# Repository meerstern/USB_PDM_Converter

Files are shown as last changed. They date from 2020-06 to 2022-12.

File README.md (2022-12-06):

# USB_PDM_Converter
USB-PDM Converter with CS53L30 &amp; CP2615

## 概要 
  * [USB オーディオブリッジIC CP2615][1]と[ADコンバータ CS53L30][2]を使用したUSB-PDM変換基板です  
  * 2個のデジタルPDM出力MEMSマイクをUSBオーディオデバイス(ステレオ)に変換します  
  * 24bit、44.1kHz/48kHzサンプリングで変換します  
  * デジタルPDM出力MEMSマイクの評価や動作確認に便利です  
  * デジタルPDM出力MEMSマイク電源は既定値で2.75Vです 
  * デジタルPDM出力MEMSマイククロックは既定値で3MHzです 
  * 2個のPDM出力MEMSマイクをUSBオーディオデバイスとして認識するためのパラメータを予め書き込んでおります  
  * OS標準のUSBオーディオデバイスとして認識されるため、ドライバは不要です  
  * [Simplicity Studio][3]を用いたCP2615のパラメータ書き換え例(デジタルMIC、アナログMIC)を用意しています  
  * [デジタル出力MEMSマイク変換基板][4]を2つ接続可能です  
  * デジタルPDM出力MEMSマイク1つの場合はモノラル出力として利用可能です  
  * サイズ40mm x50mm、M3穴x2、間隔34mm  

## 注意
  * PDM出力マイクは付属しておりませんので別途ご用意ください  
  * CS53L30の設定を変更する場合はCP2615のパラメータ変更が必要です  
  * 本変換基板とPDM出力マイクとの接続ケーブルはノイズ低減のため、30mm程度以下にしてください  
  * CP2615のパラメータを変更する場合は[Simplicity Studio][3]が必要です  
  * CP2615のパラメータを変更する場合はPIDを0xEA93に変更したCP2112が必要です  
  * CS53L30は4つのマイクを接続可能ですが、CP2615の制約で同時接続できるマイクは最大2つです  
  * MIC2側を使用する場合はR3をRX1に置き換えてください  
  * アナログMEMSマイクを使用する場合はCP2615のパラメータ書き換えが必要です  
  * CP2615はFlashベースのため、パラメータ変更の回数制約はありません  
 
## 販売サイト
  * [スイッチサイエンス][5]

## 告知
  * CP2615は生産完了予定品となっています 新規開発用途には向いていません  
  * 21年8月から22年4月頃販売の製品の一部に誤ったパラメータが書き込まれた製品があることが判明しました  
  * 購入後、マイクとして動作しない等が見られた場合はお手数ですがCrescentまでお問い合わせください  

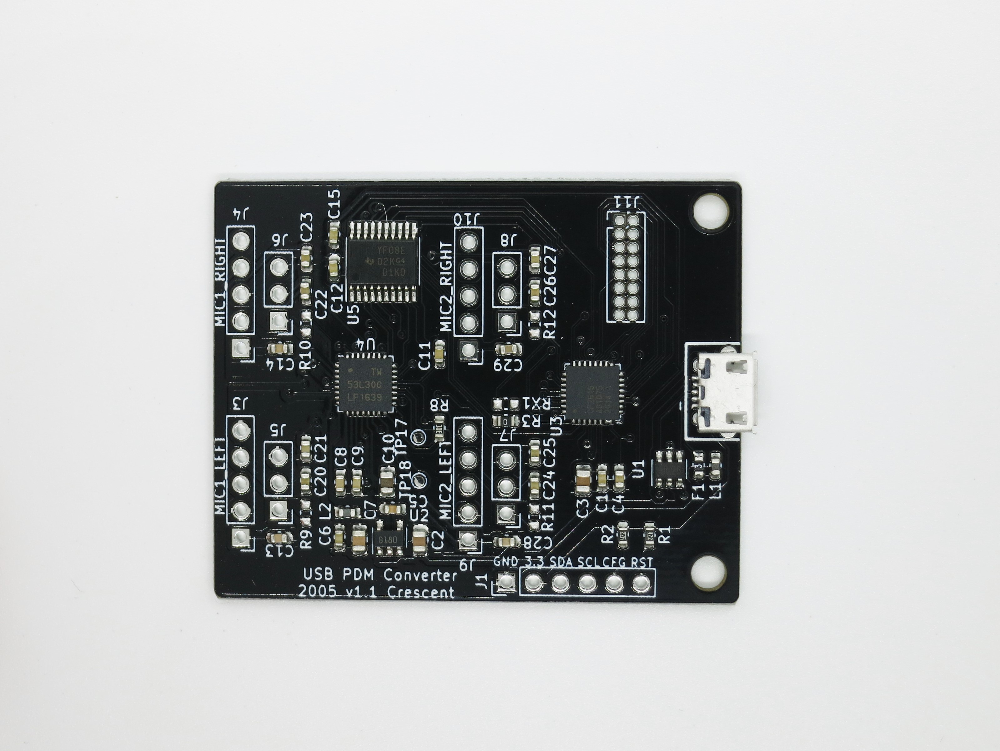
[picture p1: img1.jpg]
   
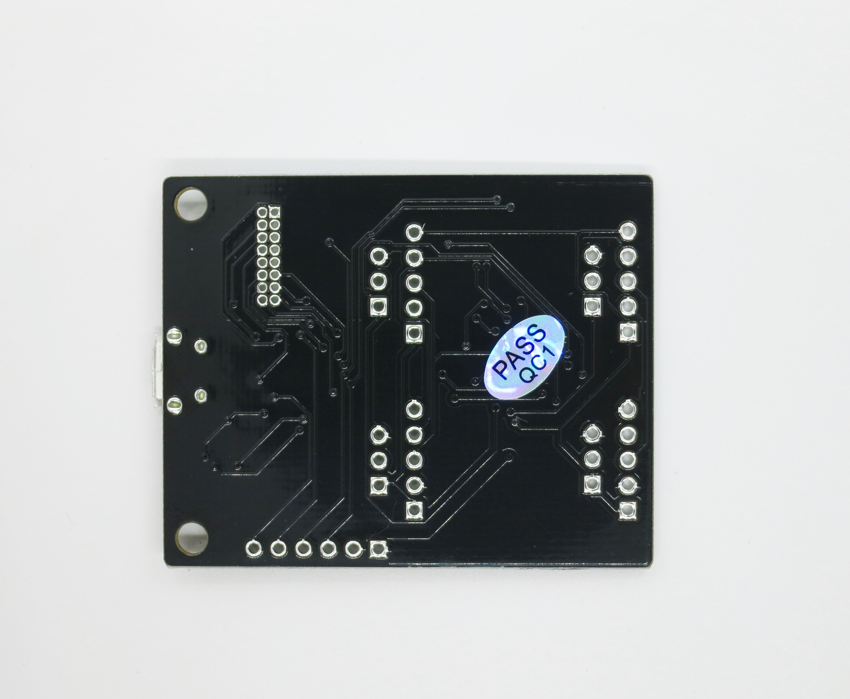
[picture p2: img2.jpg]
   
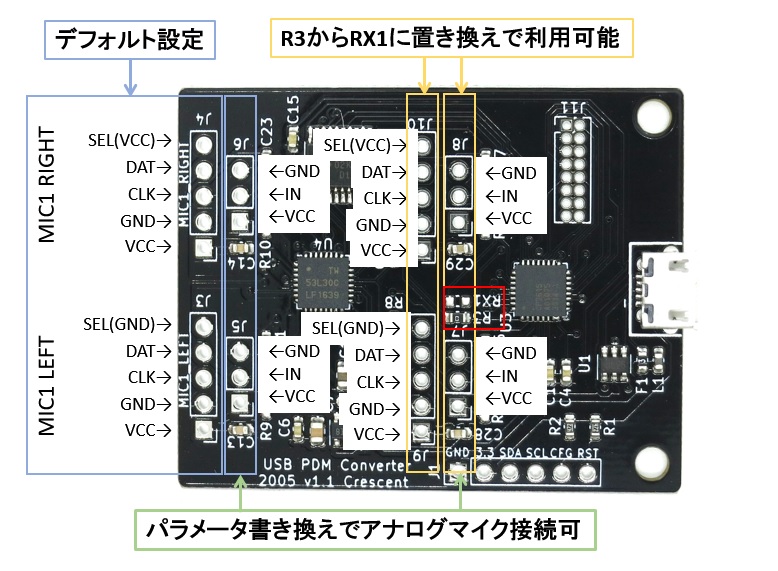
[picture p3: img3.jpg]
   
  
[1]: https://jp.silabs.com/interface/usb-audio-bridges/device.cp2615
[2]: https://www.cirrus.com/products/cs53l30/
[3]: https://jp.silabs.com/products/development-tools/software/simplicity-studio
[4]: https://www.switch-science.com/catalog/3379/
[5]: https://www.switch-science.com/products/6488

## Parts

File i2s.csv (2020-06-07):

ID | 参照記号 | パッケージ | 数 | 名称 | Supplier and ref
1 | U5 | TSSOP-20_4.4x6.5mm_P0.65mm | 1 | TXS0108EPW
2 | C15,C12,C11,C9,C6,C1 | C_0603_1608Metric | 6 | 0.1u
3 | J11 | PinHeader_2x08_P1.27mm_Vertical | 1 | Conn_02x08_Odd_Even
4 | TP18 | TestPoint_Pad_D1.0mm | 1 | MUTE
5 | TP17 | TestPoint_Pad_D1.0mm | 1 | SYNC
6 | RX1,R3 | R_0603_1608Metric | 2 | 0
7 | L2,L1 | L_0603_1608Metric | 2 | Ferrite Beads
8 | C3,C10 | C_0805_2012Metric | 2 | 4.7u
9 | REF1,REF2 | MountingHole_3.2mm_M3 | 2 | MountingHole_3.2mm_M3
10 | U4 | QFN-32-1EP_5x5mm_P0.5mm_EP3.1x3.1mm | 1 | CS53L30CZ
11 | U3 | QFN-32-1EP_5x5mm_P0.5mm_EP3.1x3.1mm | 1 | CP2615
12 | U2 | SOT-23-5 | 1 | LD3985M18R_SOT23
13 | U1 | SOT-23-6 | 1 | USBLC6-2
14 | R12,R11,R10,R9 | R_0603_1608Metric | 4 | NM
15 | R8 | R_0603_1608Metric | 1 | 20k
16 | R2,R1 | R_0603_1608Metric | 2 | 4.7k
17 | J10 | PinHeader_1x05_P2.54mm_Vertical | 1 | MIC2_RIGHT
18 | J9 | PinHeader_1x05_P2.54mm_Vertical | 1 | MIC2_LEFT
19 | J8 | PinHeader_1x03_P2.54mm_Vertical | 1 | MIC4
20 | J7 | PinHeader_1x03_P2.54mm_Vertical | 1 | MIC3
21 | J6 | PinHeader_1x03_P2.54mm_Vertical | 1 | MIC2
22 | J5 | PinHeader_1x03_P2.54mm_Vertical | 1 | MIC1
23 | J4 | PinHeader_1x05_P2.54mm_Vertical | 1 | MIC1_RIGHT
24 | J3 | PinHeader_1x05_P2.54mm_Vertical | 1 | MIC1_LEFT
25 | J2 | CONN-10118194-0001LF-FCI | 1 | USB_B_Micro
26 | J1 | PinHeader_1x06_P2.54mm_Vertical | 1 | Cfg
27 | F1 | Fuse_0603_1608Metric | 1 | Fuse
28 | C29,C28,C14,C13 | C_0603_1608Metric | 4 | 0.47u
29 | C27,C26,C25,C24,C23,C22,C21,C20,C4 | C_0603_1608Metric | 9 | 1u
30 | C8 | C_0603_1608Metric | 1 | 2.2u
31 | C7,C2 | C_0805_2012Metric | 2 | 10u
32 | C5 | C_0603_1608Metric | 1 | 0.01u

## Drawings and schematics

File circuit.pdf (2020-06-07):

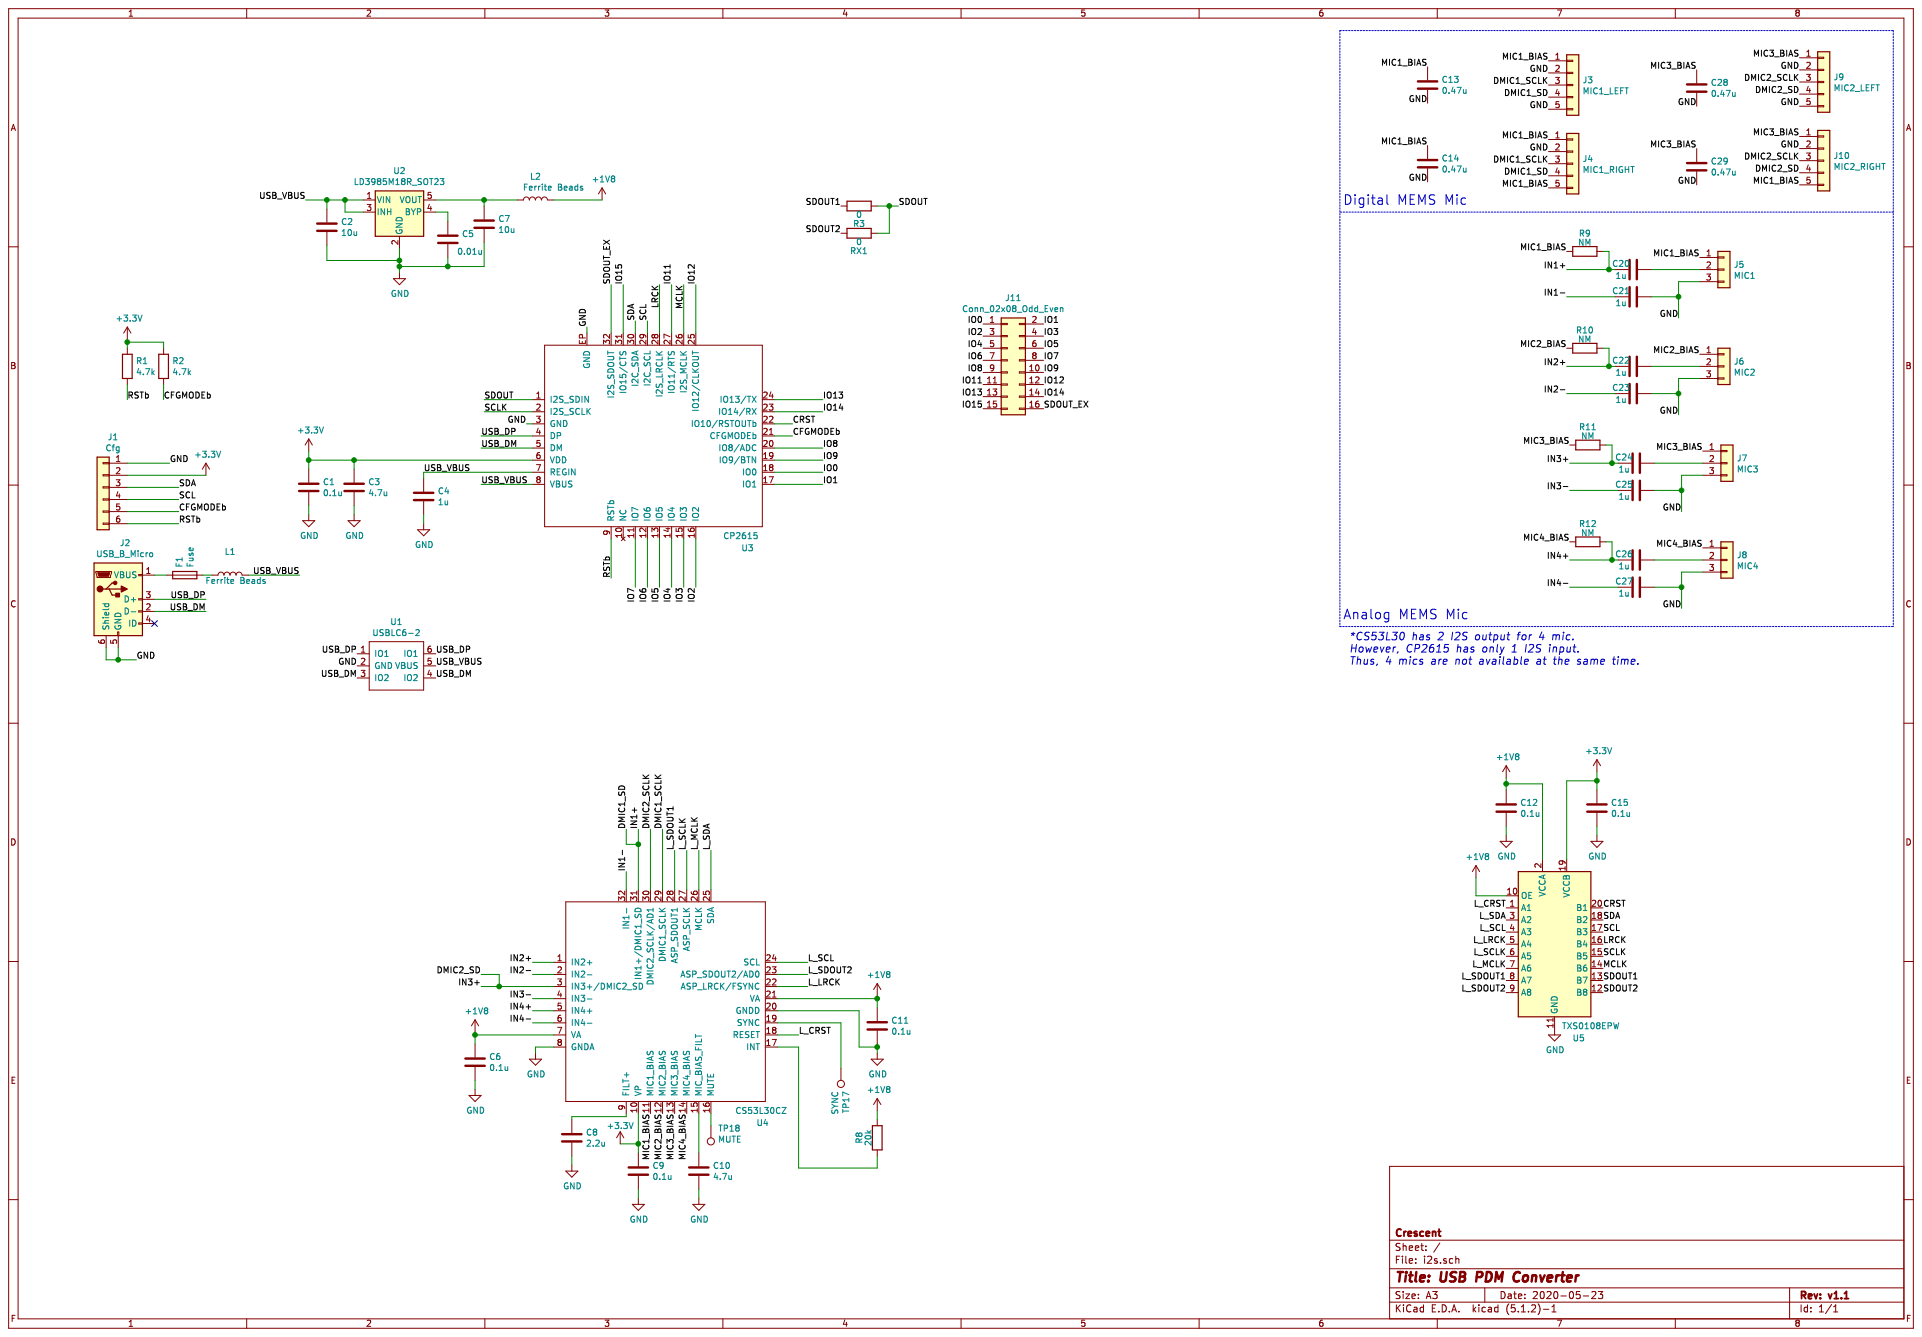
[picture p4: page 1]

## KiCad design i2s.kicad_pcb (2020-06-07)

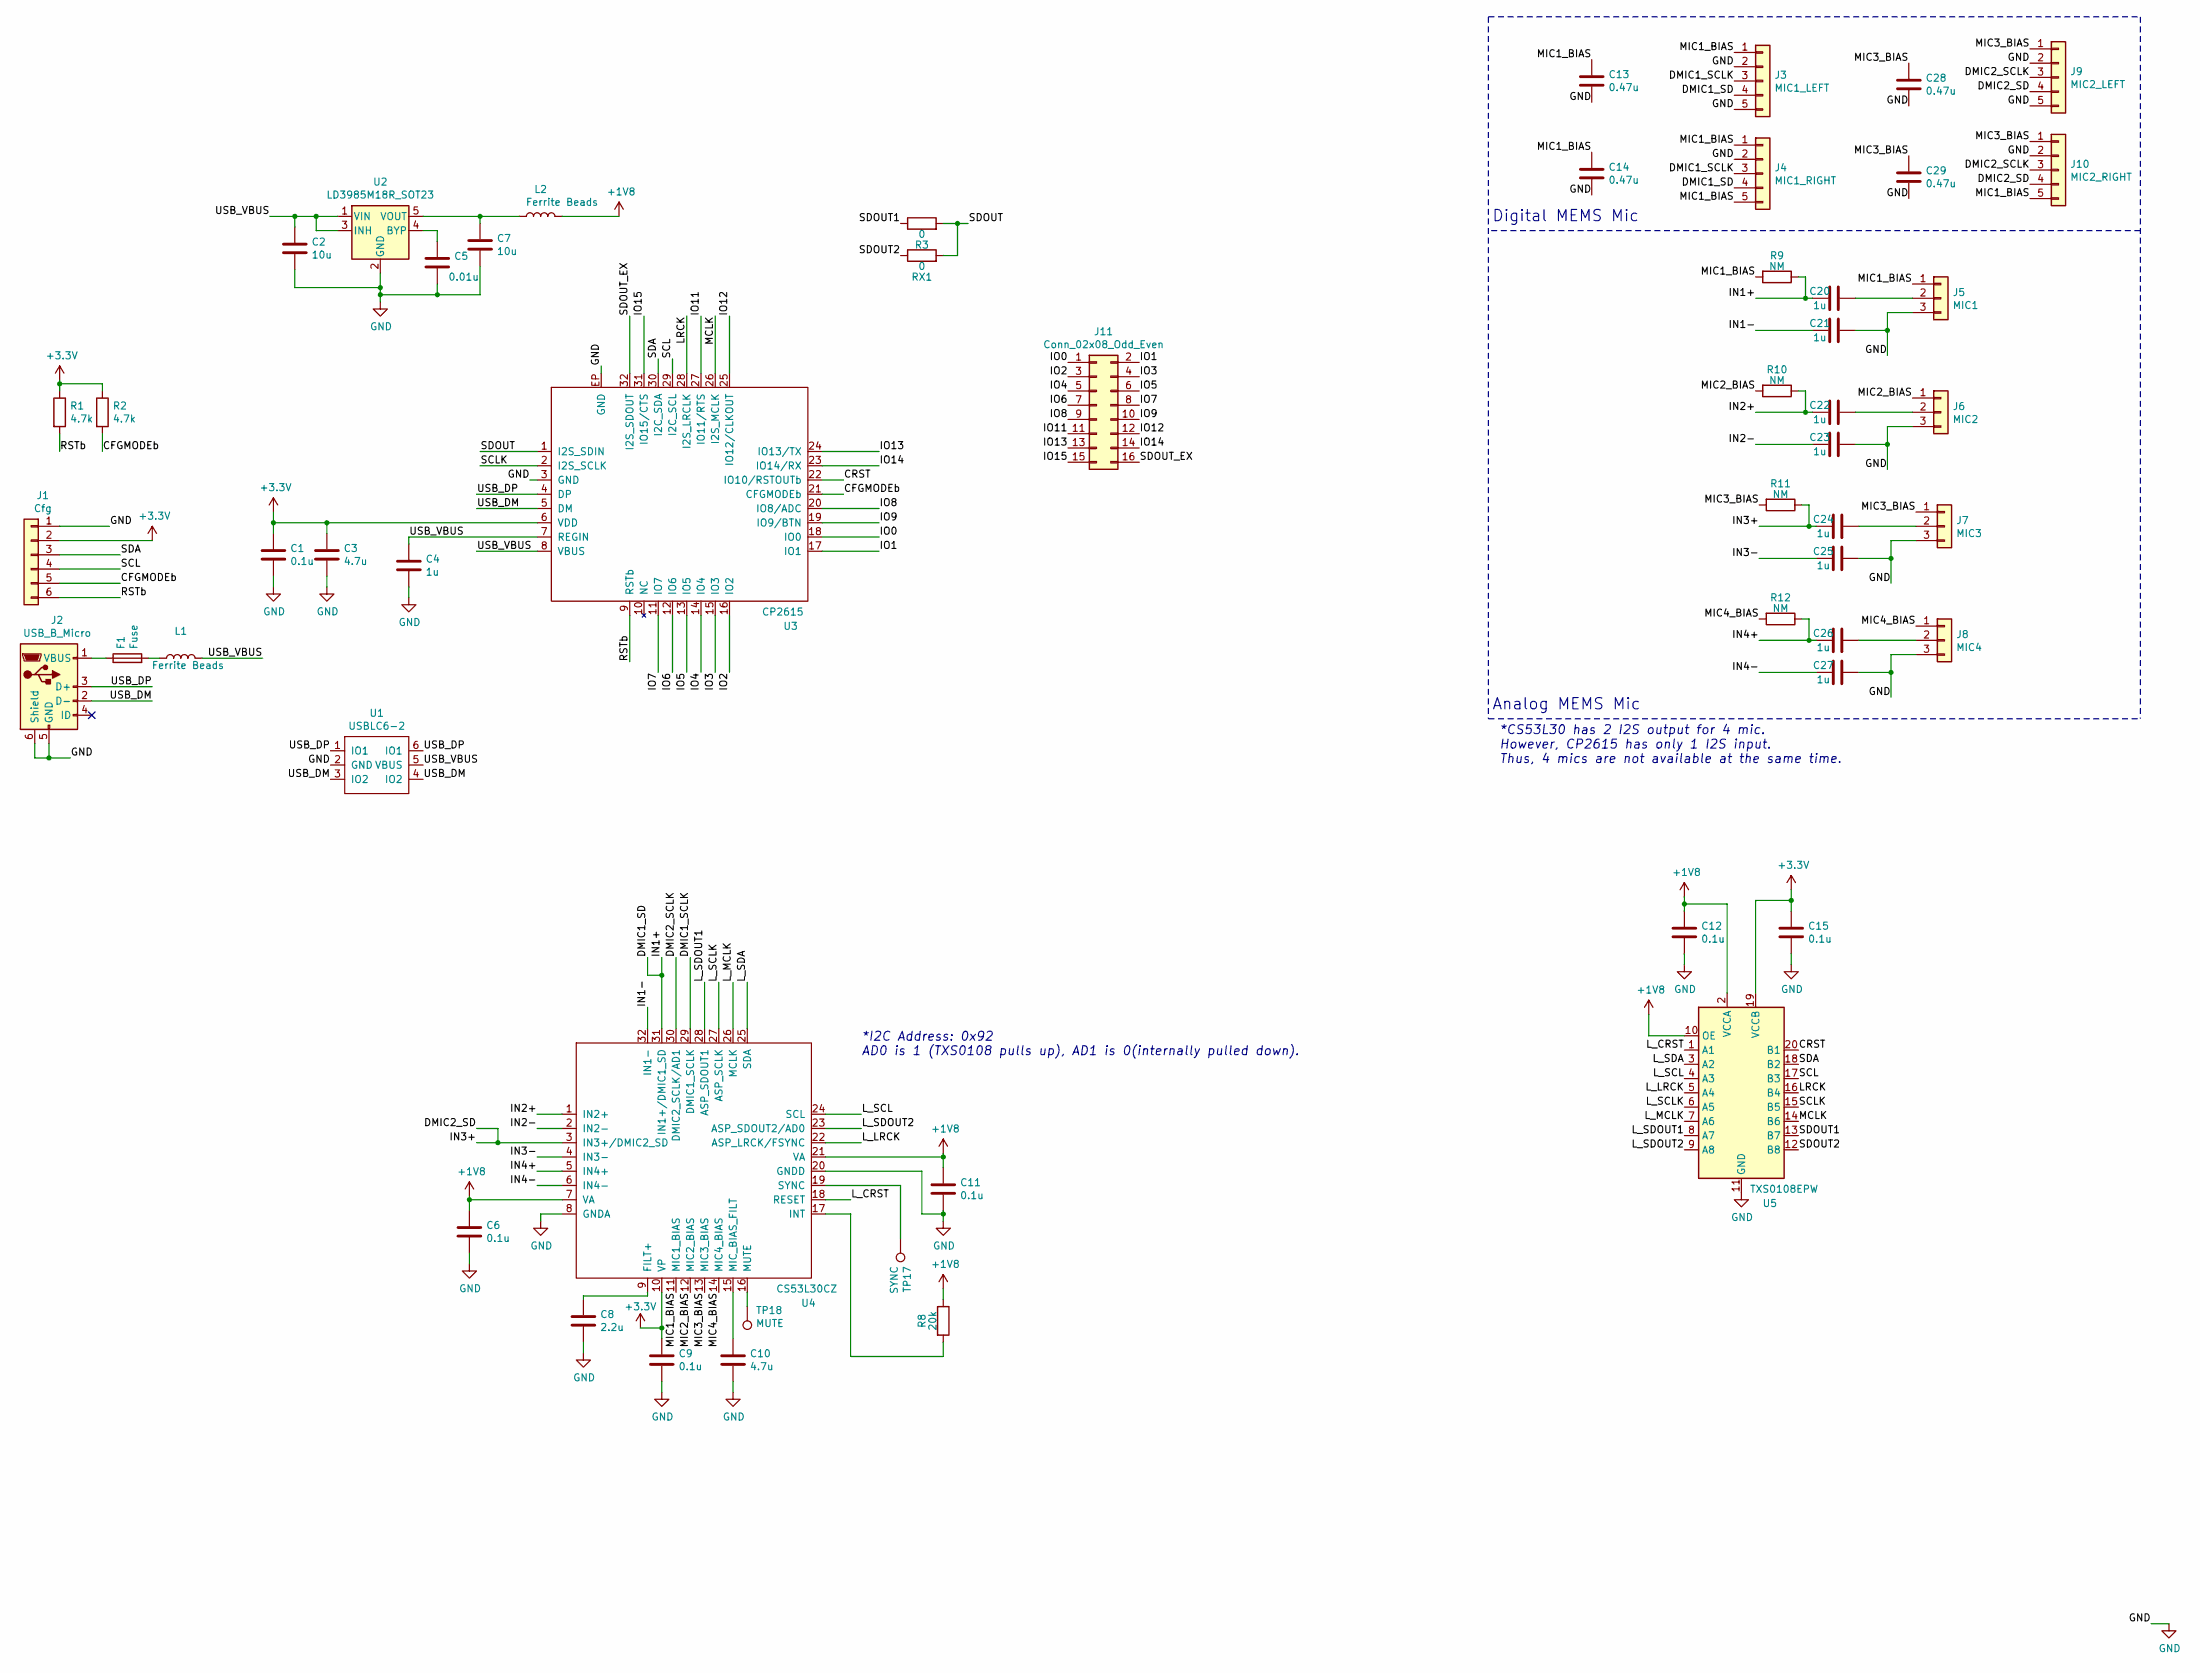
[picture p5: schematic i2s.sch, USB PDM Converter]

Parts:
C1, C6, C9, C11, C12, C15: 0.1u; C_0603_1608Metric
C2, C7: 10u; C_0805_2012Metric
C3, C10: 4.7u; C_0805_2012Metric
C4, C20, C21, C22, C23, C24, C25, C26, C27: 1u; C_0603_1608Metric
C5: 0.01u; C_0603_1608Metric
C8: 2.2u; C_0603_1608Metric
C13, C14, C28, C29: 0.47u; C_0603_1608Metric
F1: Fuse; Fuse_0603_1608Metric
J1: Cfg; PinHeader_1x06_P2.54mm_Vertical
J2: USB_B_Micro; CONN-10118194-0001LF-FCI
J3: MIC1_LEFT; PinHeader_1x05_P2.54mm_Vertical
J4: MIC1_RIGHT; PinHeader_1x05_P2.54mm_Vertical
J5: MIC1; PinHeader_1x03_P2.54mm_Vertical
J6: MIC2; PinHeader_1x03_P2.54mm_Vertical
J7: MIC3; PinHeader_1x03_P2.54mm_Vertical
J8: MIC4; PinHeader_1x03_P2.54mm_Vertical
J9: MIC2_LEFT; PinHeader_1x05_P2.54mm_Vertical
J10: MIC2_RIGHT; PinHeader_1x05_P2.54mm_Vertical
J11: Conn_02x08_Odd_Even; PinHeader_2x08_P1.27mm_Vertical
L1, L2: Ferrite Beads; L_0603_1608Metric
R1, R2: 4.7k; R_0603_1608Metric
R3: 0; R_0603_1608Metric
R8: 20k; R_0603_1608Metric
R9, R10, R11, R12: NM; R_0603_1608Metric
RX1: 0; R_0603_1608Metric
TP17: SYNC; TestPoint_Pad_D1.0mm
TP18: MUTE; TestPoint_Pad_D1.0mm
U1: USBLC6-2; SOT-23-6
U2: LD3985M18R_SOT23; SOT-23-5
U3: CP2615; QFN-32-1EP_5x5mm_P0.5mm_EP3.1x3.1mm
U4: CS53L30CZ; QFN-32-1EP_5x5mm_P0.5mm_EP3.1x3.1mm
U5: TXS0108EPW; TSSOP-20_4.4x6.5mm_P0.65mm

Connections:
+1V8: C6.1, C11.1, C12.1, L2.2, R8.1, U4.7 (VA), U4.21 (VA), U5.2 (VCCA), U5.10 (OE)
+3V3: C1.1, C3.1, C9.1, C15.1, J1.2, R1.1, R2.1, U3.6 (VDD), U4.10 (VP), U5.19 (VCCB)
/CFGMODEb: J1.5, R2.2, U3.21 (CFGMODEb)
/CRST: U3.22 (IO10/RSTOUTb), U5.20 (B1)
/DMIC1_SCLK: J3.3, J4.3, U4.29 (DMIC1_SCLK)
/DMIC1_SD: C20.2, J3.4, J4.4, R9.1, U4.31 (IN1+/DMIC1_SD)
/DMIC2_SCLK: J9.3, J10.3, U4.30 (DMIC2_SCLK/AD1)
/DMIC2_SD: C24.2, J9.4, J10.4, R11.1, U4.3 (IN3+/DMIC2_SD)
/IN1-: C21.2, U4.32 (IN1-)
/IN2+: C22.2, R10.1, U4.1 (IN2+)
/IN2-: C23.2, U4.2 (IN2-)
/IN3-: C25.2, U4.4 (IN3-)
/IN4+: C26.2, R12.1, U4.5 (IN4+)
/IN4-: C27.2, U4.6 (IN4-)
/IO0: J11.1, U3.18 (IO0)
/IO1: J11.2, U3.17 (IO1)
/IO2: J11.3, U3.16 (IO2)
/IO3: J11.4, U3.15 (IO3)
/IO4: J11.5, U3.14 (IO4)
/IO5: J11.6, U3.13 (IO5)
/IO6: J11.7, U3.12 (IO6)
/IO7: J11.8, U3.11 (IO7)
/IO8: J11.9, U3.20 (IO8/ADC)
/IO9: J11.10, U3.19 (IO9/BTN)
/IO11: J11.11, U3.27 (IO11/RTS)
/IO12: J11.12, U3.25 (IO12/CLKOUT)
/IO13: J11.13, U3.24 (IO13/TX)
/IO14: J11.14, U3.23 (IO14/RX)
/IO15: J11.15, U3.31 (IO15/CTS)
/LRCK: U3.28 (I2S_LRCLK), U5.16 (B4)
/L_CRST: U4.18 (RESET), U5.1 (A1)
/L_LRCK: U4.22 (ASP_LRCK/FSYNC), U5.5 (A4)
/L_MCLK: U4.26 (MCLK), U5.7 (A6)
/L_SCL: U4.24 (SCL), U5.4 (A3)
/L_SCLK: U4.27 (ASP_SCLK), U5.6 (A5)
/L_SDA: U4.25 (SDA), U5.3 (A2)
/L_SDOUT1: U4.28 (ASP_SDOUT1), U5.8 (A7)
/L_SDOUT2: U4.23 (ASP_SDOUT2/AD0), U5.9 (A8)
/MCLK: U3.26 (I2S_MCLK), U5.14 (B6)
/MIC1_BIAS: C13.1, C14.1, J3.1, J4.1, J4.5, J5.1, J10.5, R9.2, U4.11 (MIC1_BIAS)
/MIC2_BIAS: J6.1, R10.2, U4.12 (MIC2_BIAS)
/MIC3_BIAS: C28.1, C29.1, J7.1, J9.1, J10.1, R11.2, U4.13 (MIC3_BIAS)
/MIC4_BIAS: J8.1, R12.2, U4.14 (MIC4_BIAS)
/RSTb: J1.6, R1.2, U3.9 (RSTb)
/SCL: J1.4, U3.29 (I2C_SCL), U5.17 (B3)
/SCLK: U3.2 (I2S_SCLK), U5.15 (B5)
/SDA: J1.3, U3.30 (I2C_SDA), U5.18 (B2)
/SDOUT: R3.2, RX1.2, U3.1 (I2S_SDIN)
/SDOUT1: R3.1, U5.13 (B7)
/SDOUT2: RX1.1, U5.12 (B8)
/SDOUT_EX: J11.16, U3.32 (I2S_SDOUT)
/USB_DM: J2.2 (D-), U1.3 (IO2), U1.4 (IO2), U3.5 (DM)
/USB_DP: J2.3 (D+), U1.1 (IO1), U1.6 (IO1), U3.4 (DP)
/USB_VBUS: C2.1, C4.1, L1.2, U1.5 (VBUS), U2.1 (VIN), U2.3 (INH), U3.7 (REGIN), U3.8 (VBUS)
GND: C1.2, C2.2, C3.2, C4.2, C5.2, C6.2, C7.2, C8.2, C9.2, C10.2, C11.2, C12.2, C13.2, C14.2, C15.2, C21.1, C23.1, C25.1, C27.1, C28.2, C29.2, J1.1, J2.5 (GND), J2.6 (Shield), J3.2, J3.5, J4.2, J5.3, J6.3, J7.3, J8.3, J9.2, J9.5, J10.2, U1.2 (GND), U2.2 (GND), U3.3 (GND), U3.33, U3.EP (GND), U4.8 (GNDA), U4.20 (GNDD), U5.11 (GND)
unnamed: C5.1, U2.4 (BYP)
unnamed: C7.1, L2.1, U2.5 (VOUT)
unnamed: C8.1, U4.9 (FILT+)
unnamed: C10.1, U4.15 (MIC_BIAS_FILT)
unnamed: C20.1, J5.2
unnamed: C22.1, J6.2
unnamed: C24.1, J7.2
unnamed: C26.1, J8.2
unnamed: F1.1, J2.1 (VBUS)
unnamed: F1.2, L1.1
unnamed: R8.2, U4.17 (INT)
unnamed: TP17.1, U4.19 (SYNC)
unnamed: TP18.1, U4.16 (MUTE)

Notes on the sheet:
Digital MEMS Mic
Analog MEMS Mic
*CS53L30 has 2 I2S output for 4 mic. However, CP2615 has only 1 I2S input. Thus, 4 mics are not available at the same time.
*I2C Address: 0x92 AD0 is 1 (TXS0108 pulls up), AD1 is 0(internally pulled down).

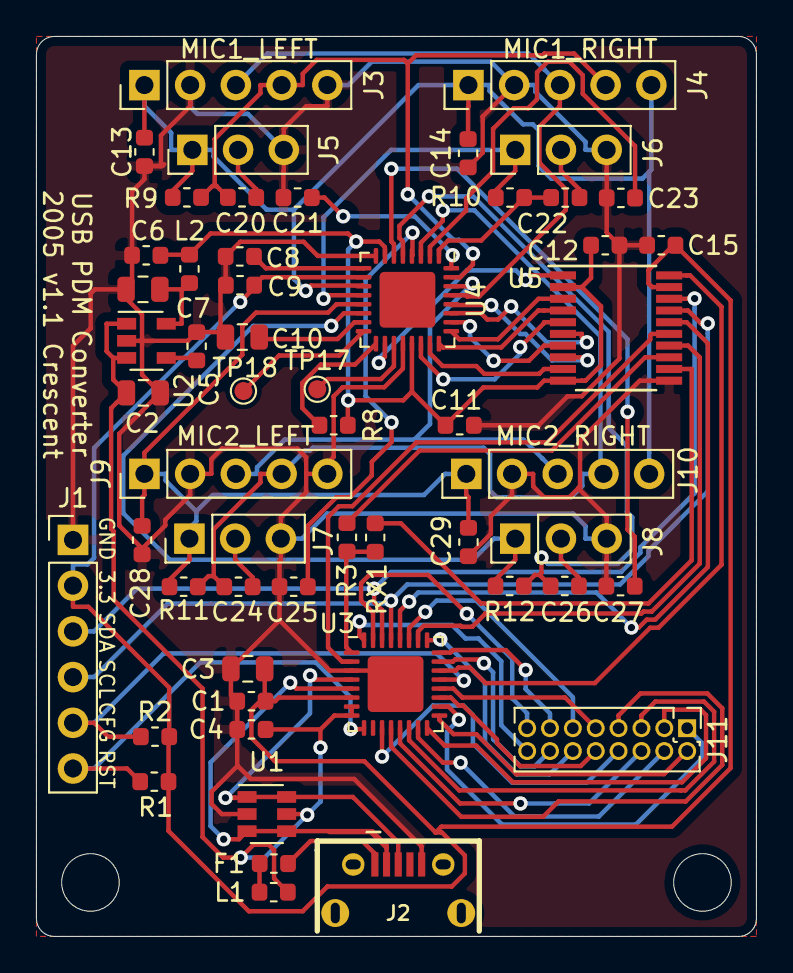
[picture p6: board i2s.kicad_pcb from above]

Board: 2 copper layers, 40.0 x 50.0 mm, 57 parts (0 on the bottom side), 68 nets.

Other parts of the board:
REF1, REF2: MountingHole_3.2mm_M3

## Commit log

2020-06-07 Add pcb data
    [i2s-B_Cu.gbr, i2s-B_Mask.gbr, i2s-B_Paste.gbr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]
2020-07-05 Add Pin image
2020-07-05 Simplicity Studio Sample Settings
